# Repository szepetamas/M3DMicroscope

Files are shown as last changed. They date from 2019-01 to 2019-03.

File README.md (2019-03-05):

# M3DMicroscope
Converting Micro+ 3D printer into scanning microscope for slides and plates.

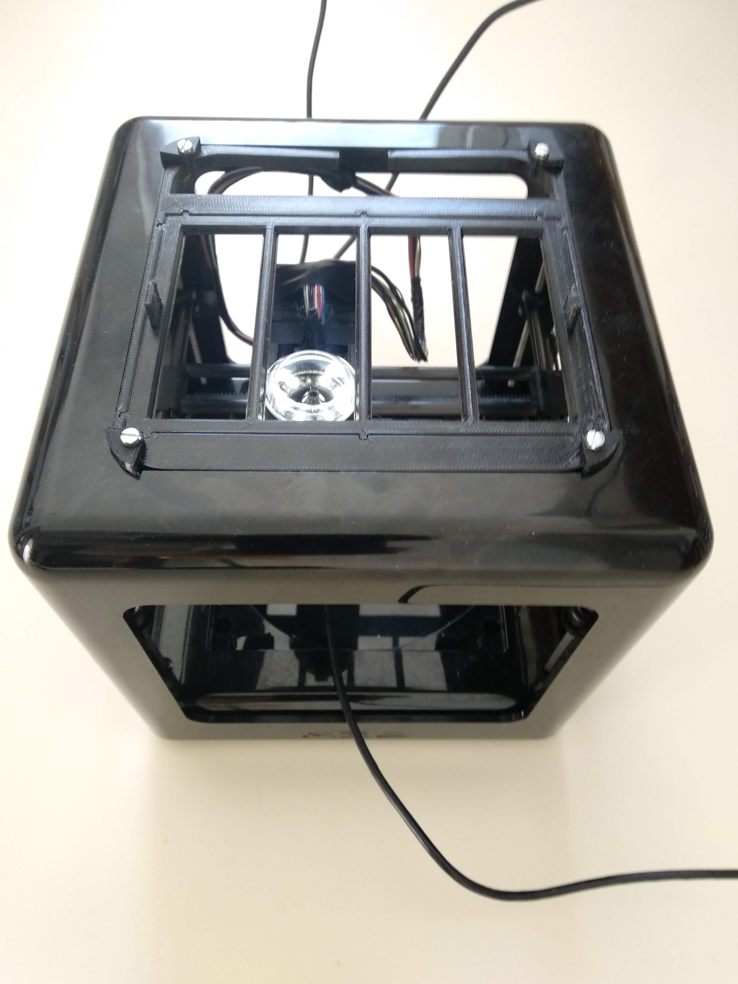
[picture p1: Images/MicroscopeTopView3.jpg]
A completed built of the M3D+ printer based microscope Title


## License

This project is free and unlicensed into the public domain.
More info in the following:

(https://github.com/szepetamas/M3DMicroscope/blob/master/LICENSE)

## Requirements

Micro+ 3D printer (or equivalent)
1600x USB microscope (or similar)
3D printed parts (https://github.com/szepetamas/M3DMicroscope/tree/master/STLFiles)
srews
tools for assembly

## Configurations

The project currently supports two main configurations
1.) 1 port plate scanner with tha main bracket
(https://github.com/szepetamas/M3DMicroscope/blob/master/Images/MainBracket.jpg)

2.) 4 port slide scanner with the slider bracket
(https://github.com/szepetamas/M3DMicroscope/blob/master/Images/SliderBracket.jpg)

## Assembly instructions for 3D printable parts

1.) Print the parts you need with your fafourite slicer software
(https://github.com/szepetamas/M3DMicroscope/blob/master/Images/PartsInSlic3r.png)

2.) Replace the door unit of the printer head
(https://github.com/szepetamas/M3DMicroscope/blob/master/Images/M3DDoor.jpg)

3.) Mount the microscope holder onto the door unit
(https://github.com/szepetamas/M3DMicroscope/blob/master/Images/MicroscopeHolder1600x.jpg)

4.) Mount the main bracket with the bracket holders onto the top of the 3D printer
(https://github.com/szepetamas/M3DMicroscope/blob/master/Images/MainBracket.jpg)
(https://github.com/szepetamas/M3DMicroscope/blob/master/Images/BracketHolder.jpg)

5.) In the M3DExpert software (came with the printer) move the head in X and Y directions, and focus with directions in Z axis
(https://github.com/szepetamas/M3DMicroscope/blob/master/Images/M3DexpertSet.png)

## Optional assembly instructions (requires a little more basic tech skills!)

The original printer cable can be rerouted under the top frame section of the 3D printer. In order to do that, you have to disassemble the pritner base, and also cut off the outer shell of the cable in order to make it more flexible.
(https://github.com/szepetamas/M3DMicroscope/blob/master/Images/MicroscopeBackView.jpg)

Also note that, based on the current design additional USB microscopes can be designed and fitted onto the printer head.

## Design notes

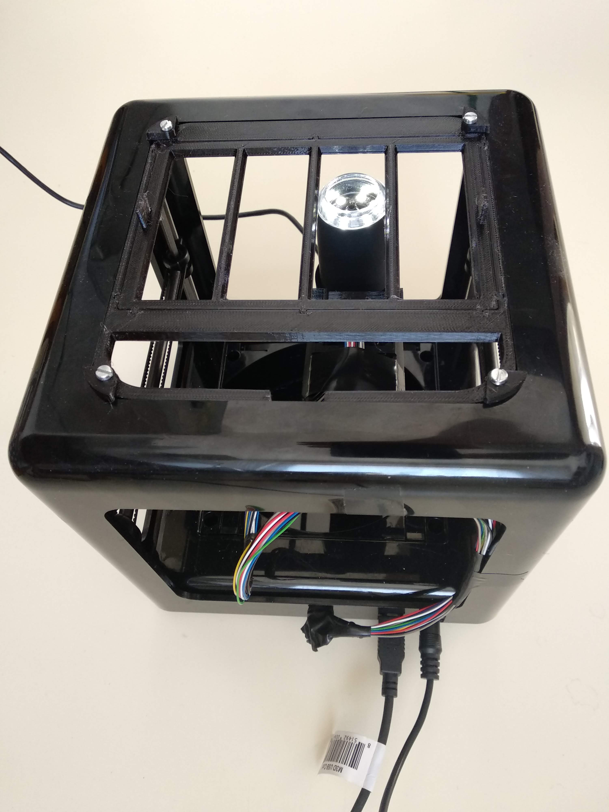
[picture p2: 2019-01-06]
Images/MicroscopeTopView2.jpg

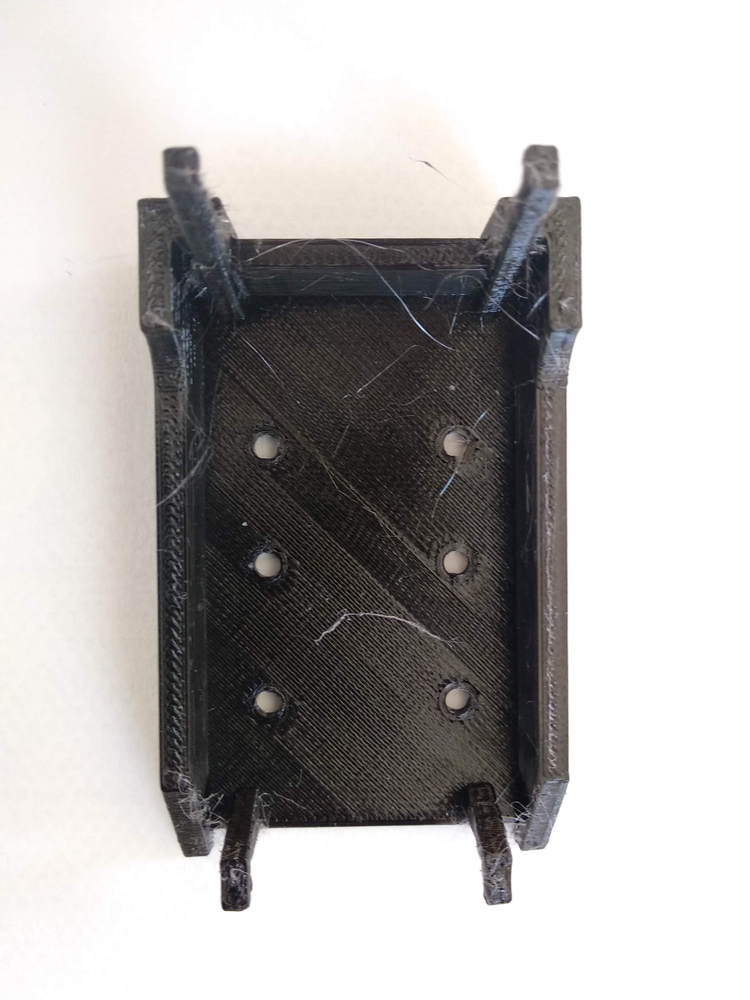
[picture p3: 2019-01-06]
Images/M3DDoor.jpg

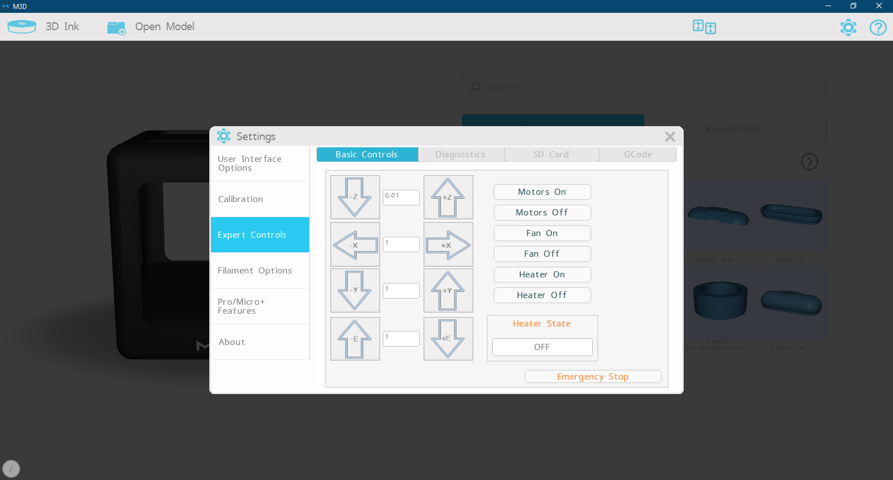
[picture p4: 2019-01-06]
Images/M3DexpertSet.png

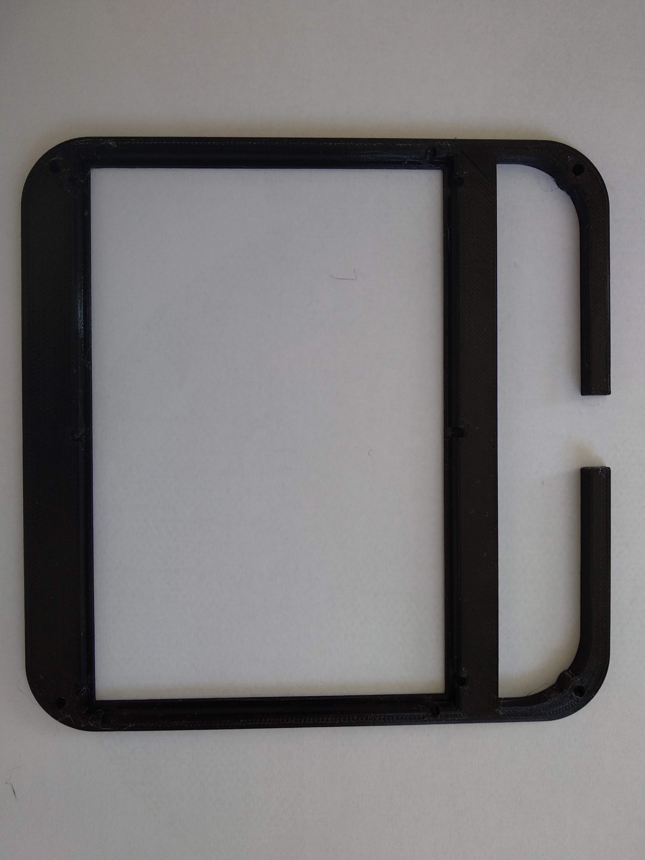
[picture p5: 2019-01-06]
Images/MainBracket.jpg

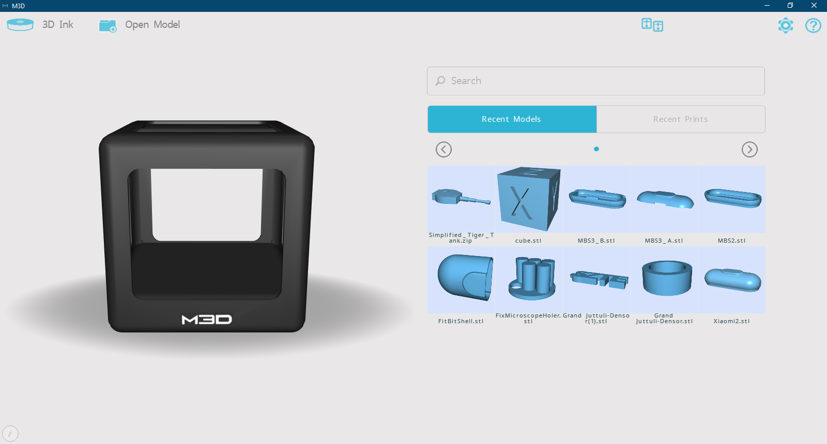
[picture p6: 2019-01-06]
Images/M3Dmain.png

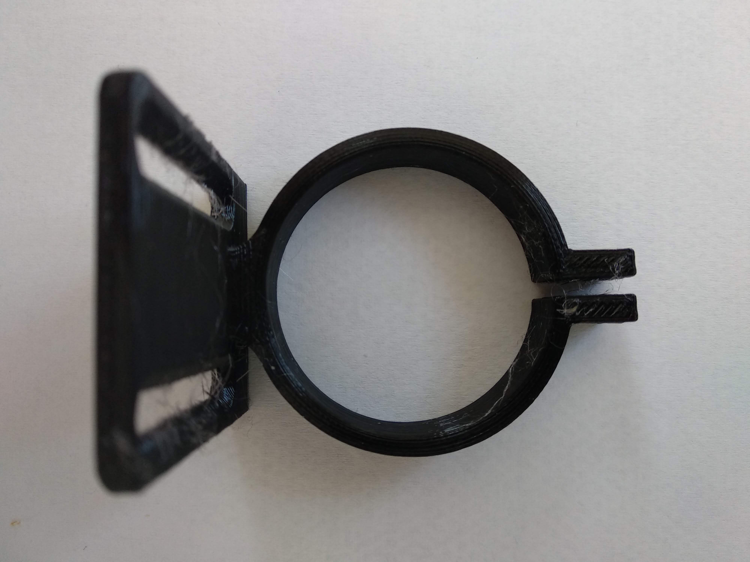
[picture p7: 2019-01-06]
Images/MicroscopeHolder1600x.jpg

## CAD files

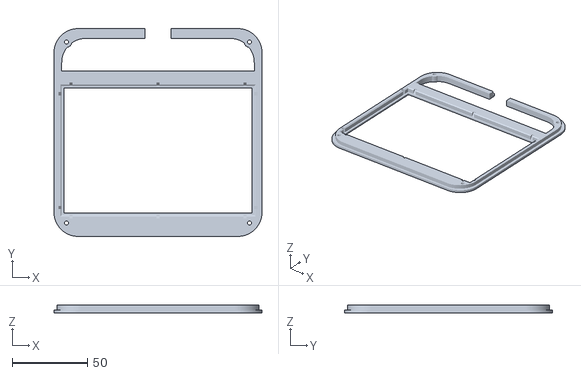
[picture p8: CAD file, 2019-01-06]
STLFiles/mainbracket.stl
138.3 x 138.2 x 5.00

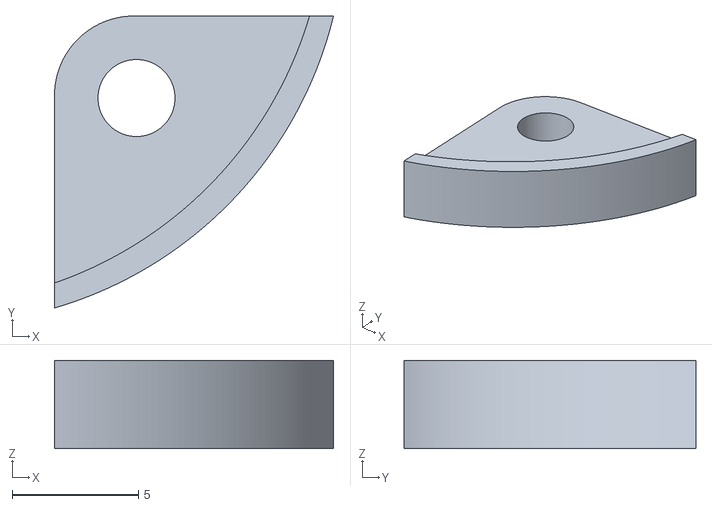
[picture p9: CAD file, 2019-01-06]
STLFiles/bracketholder.stl
11.1 x 11.6 x 3.50

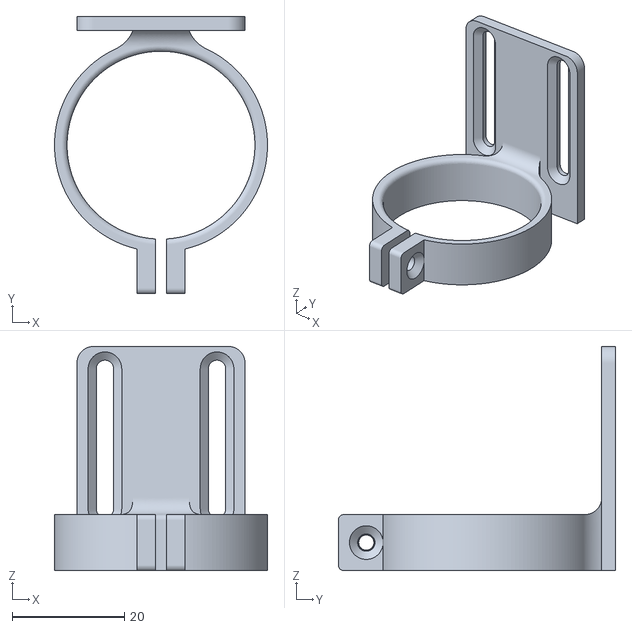
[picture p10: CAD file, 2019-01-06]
STLFiles/microscopeholder1600x.stl
38.0 x 49.5 x 40.0

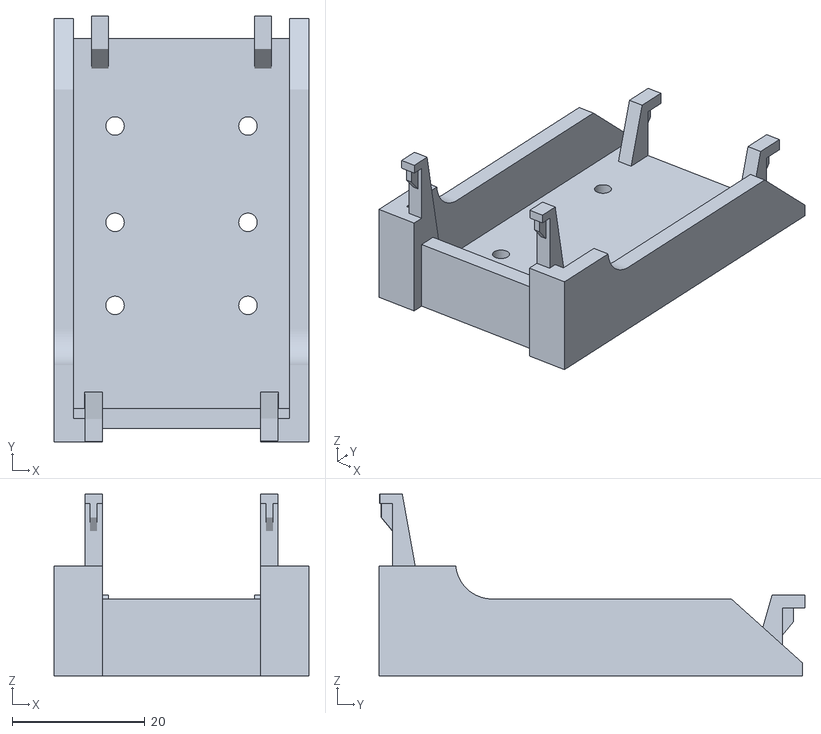
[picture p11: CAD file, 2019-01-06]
STLFiles/m3ddoorwithsupport.stl
38.4 x 64.1 x 27.4

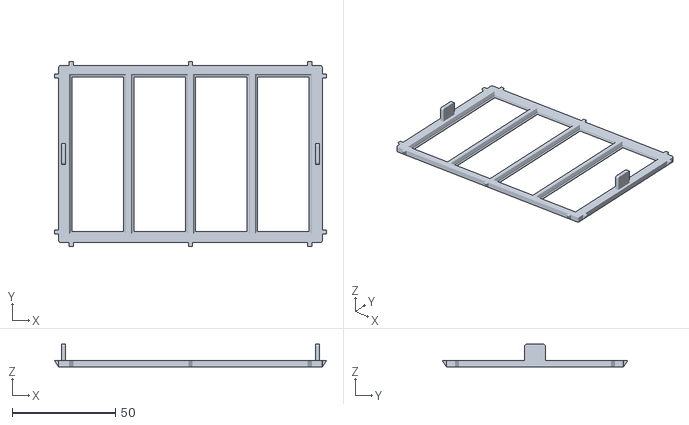
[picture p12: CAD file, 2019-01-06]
STLFiles/sliderbracket.stl
131.9 x 89.9 x 11.0

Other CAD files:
STLFiles/m3ddoorwithoutsupport.stl

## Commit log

2019-01-06 STL files to print
    Required to print:
    mainbracket: 1pcs
    m3ddoorwithsupport / m3ddoorwithoutsupport: 1pcs
    sliderbracket: 1pcs
    bracketholder: 4pcs
    [bracketholder.stl, m3ddoorwithoutsupport.stl, m3ddoorwithsupport.stl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]
2019-01-06 Printed parts and screenshots
